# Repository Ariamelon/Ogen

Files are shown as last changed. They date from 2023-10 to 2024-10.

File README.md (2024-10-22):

# Ogen Lite
A PMW3360 breakout board. Lite version without shift registers which only works with up to 3v3 VCC and logic.

## Disclaimer
This board is licensed under CERN-OHL-S-2.0.

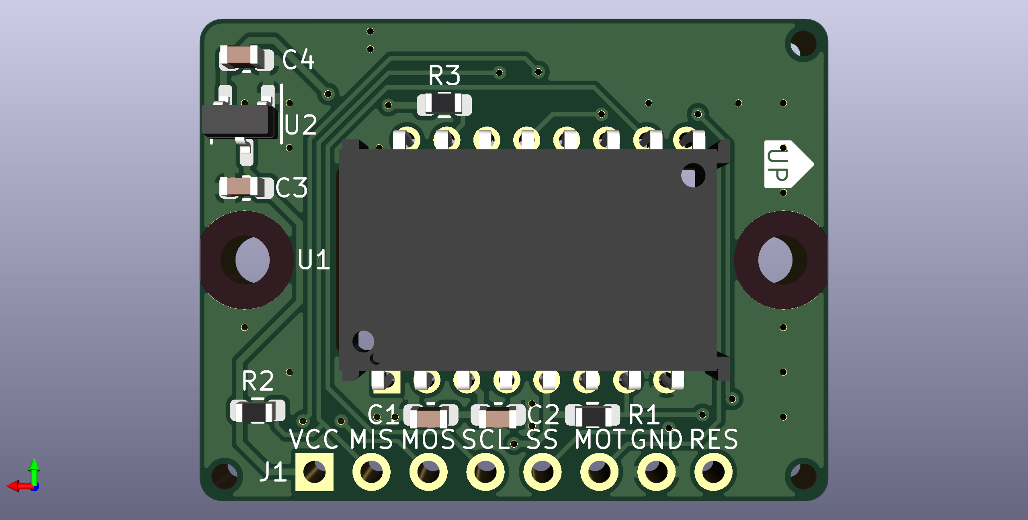
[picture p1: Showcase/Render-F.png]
Render Front

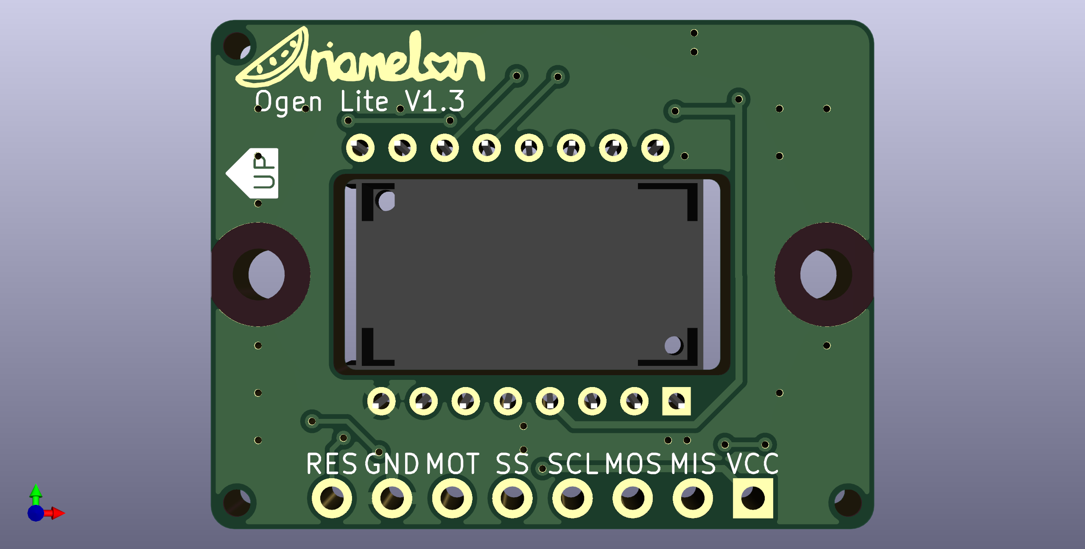
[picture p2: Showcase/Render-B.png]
Render Back


 ## Changelog
 * 22/10/2024: License updated to CERN-OHL-S-2.0.
 * 14/10/2023: V1.3 update. Changed LDO to XC6206P202MR.
 * 18/09/2023: Fixed .gitignore file. Changed LDO capacitors to 4u7 to match the one used in the PMW3360.
 * 04/08/2023: Updated to V1.1. Changed capacitors and resistors to 0603. Stitched ground planes together. Removed MISO pullup jumper (MISO is pulled up by default now). Added metadata to schematic and PCB file. Changed location of production files for easier access. 
 * 29/03/2023: Changed logo.
 * 21/03/2023: V1.0 Lite initial commit. No shift registers on board, hence works with 3V3 only.

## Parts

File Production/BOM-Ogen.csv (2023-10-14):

Comment | Designator | Footprint | LCSC
100n | C2 | C_0603_1608Metric | C14663
4u7 | C1,C3,C4 | C_0603_1608Metric | C19666
39 | R3 | R_0603_1608Metric | C25236
10k | R1,R2 | R_0603_1608Metric | C25804
XC6206P202MR | U2 | SOT-23-3 | C2891260
PMW3360DM-T2QU | U1 | IC_PMW3360DM-T2QU

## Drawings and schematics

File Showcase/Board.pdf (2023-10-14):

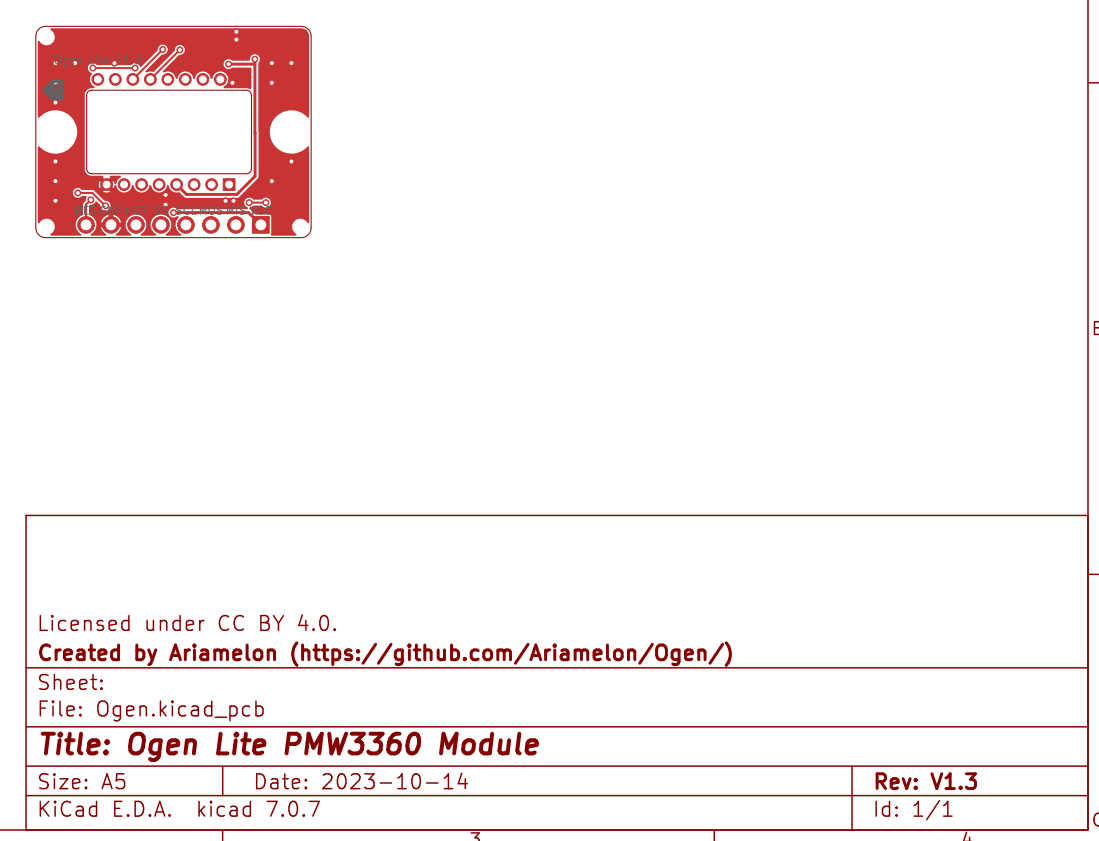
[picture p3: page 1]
MOT SS SCL MOS Ogen Lite V1.3 RESGND; MIS VCC 1; BC Date: 2023-10-14 KiCad; kicad; 7.0.7 Size: A5; Rev: V1.3; File: Ogen.kicad_pcb Sheet: Created; by Ariamelon; (https://github.com/Ariamelon/Ogen/) Licensed; under CC

Id: 1/1 Title: Ogen Lite PMW3360 Module

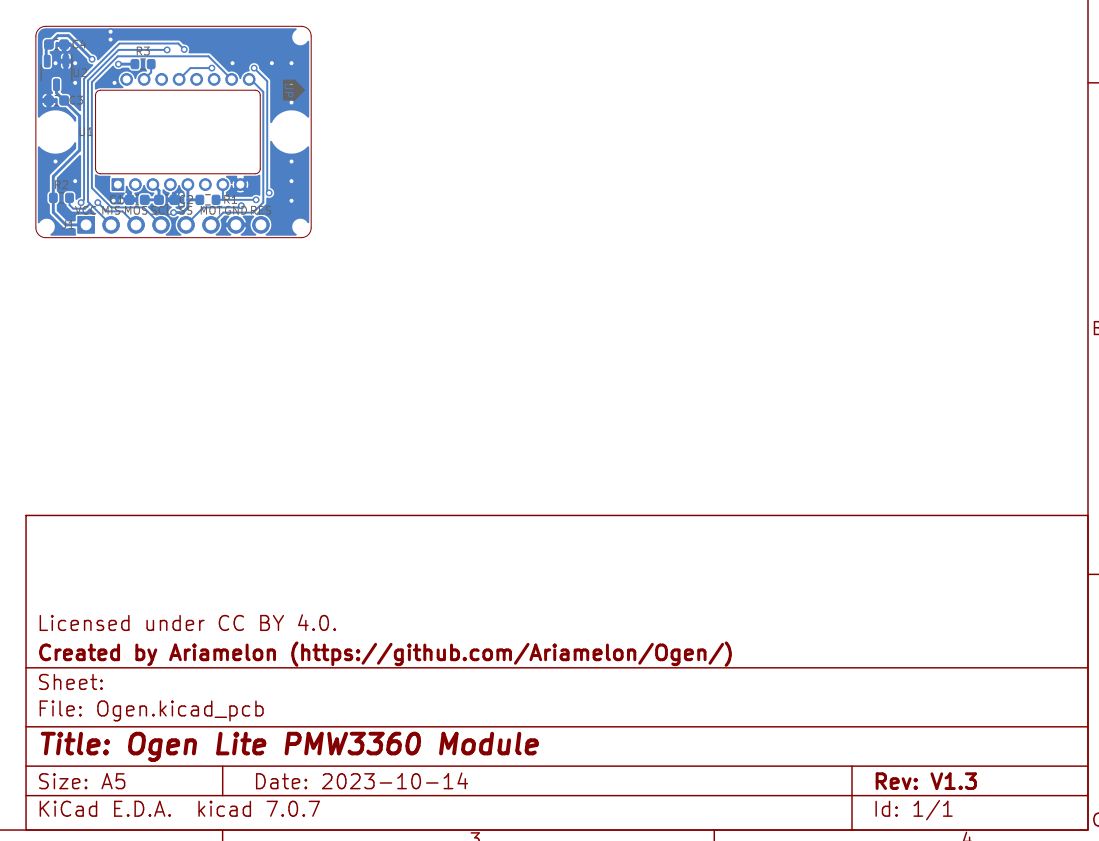
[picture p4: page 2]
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

Id: 1/1 Title: Ogen Lite PMW3360 Module

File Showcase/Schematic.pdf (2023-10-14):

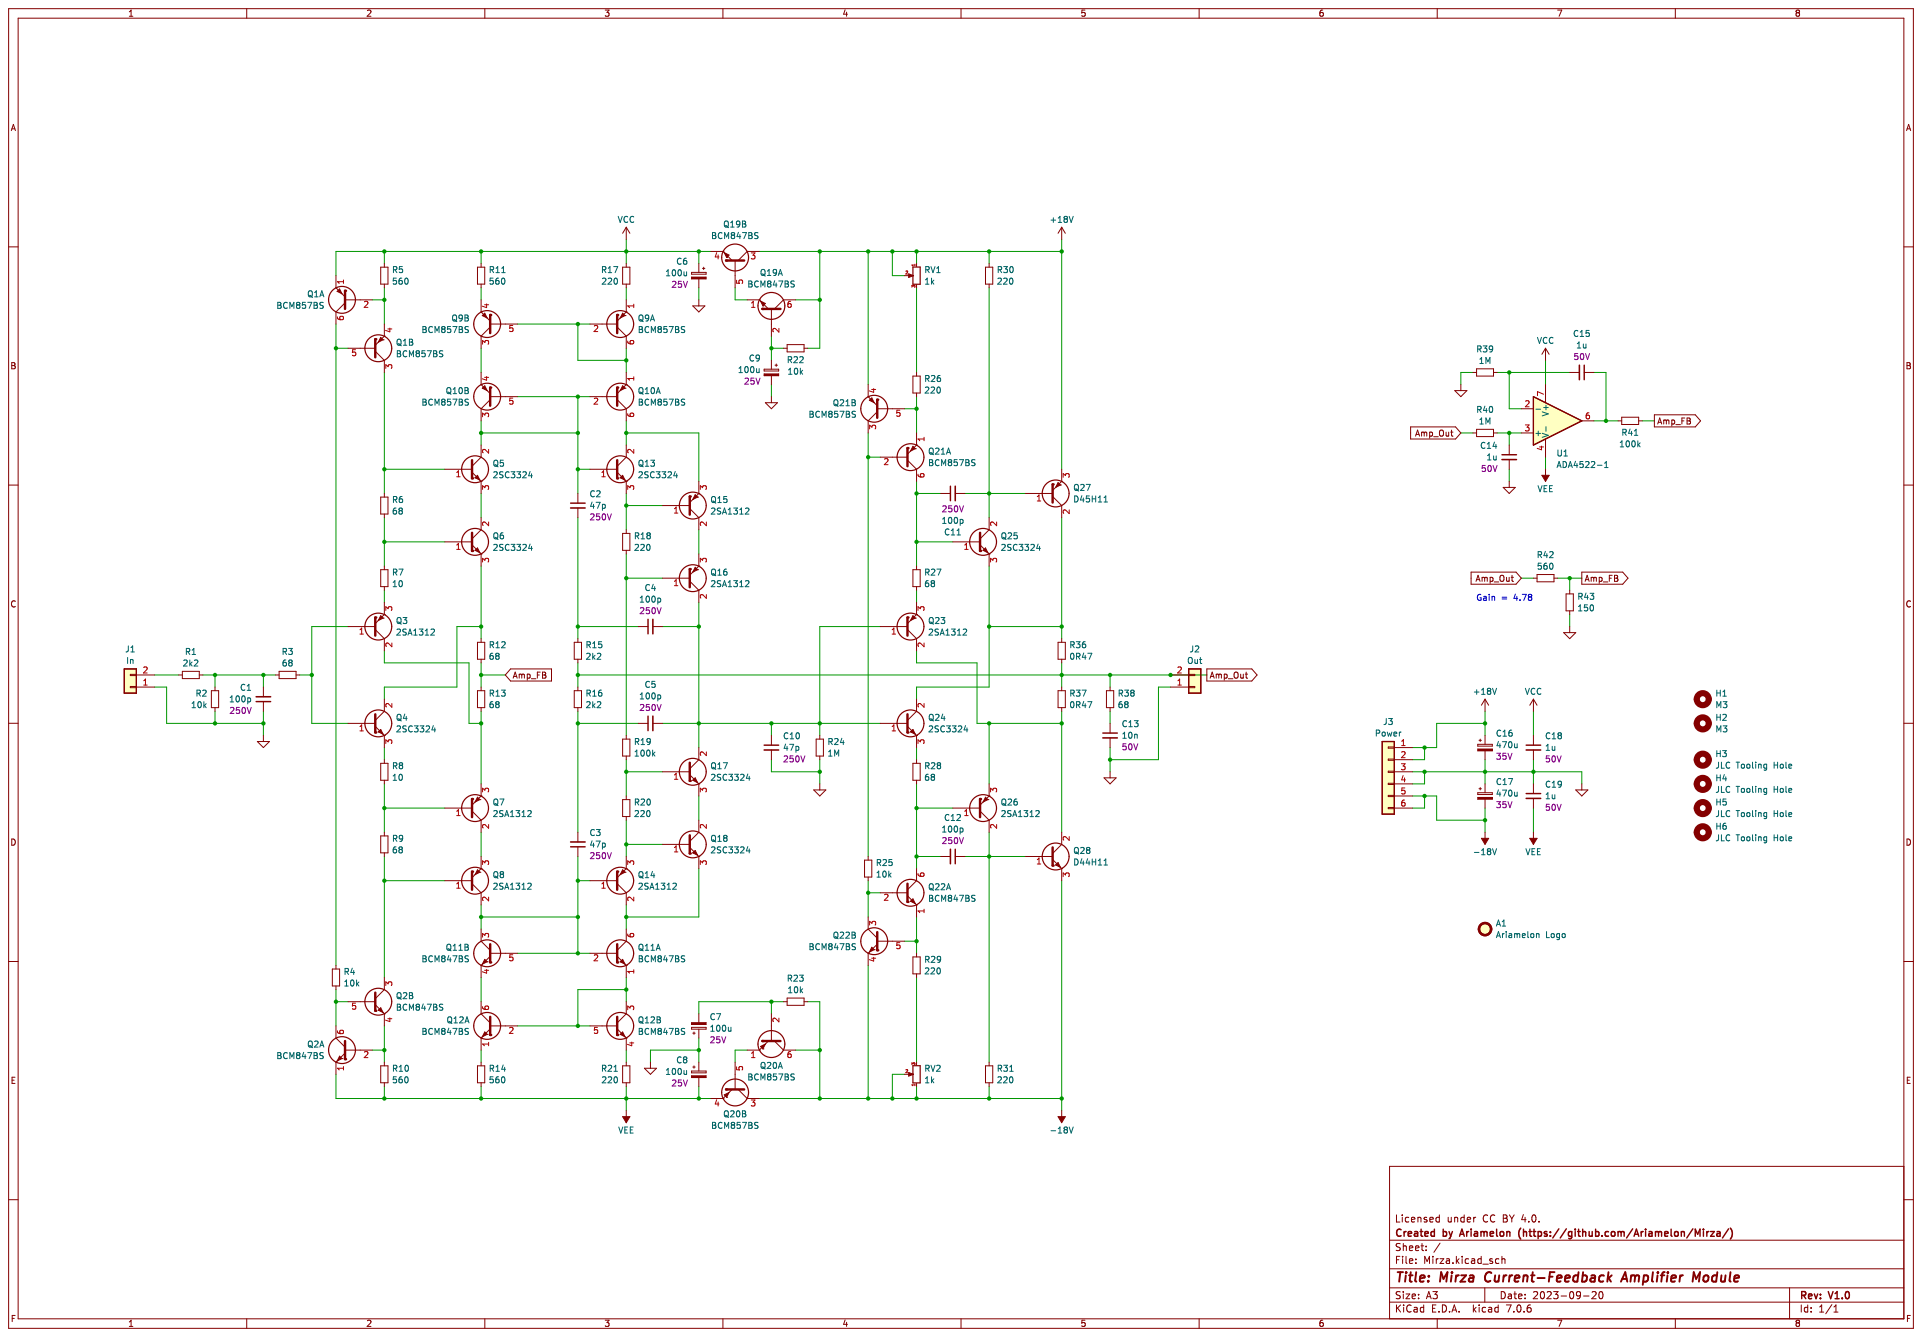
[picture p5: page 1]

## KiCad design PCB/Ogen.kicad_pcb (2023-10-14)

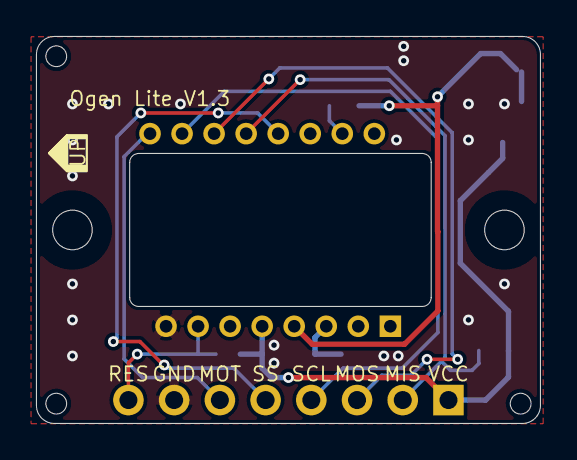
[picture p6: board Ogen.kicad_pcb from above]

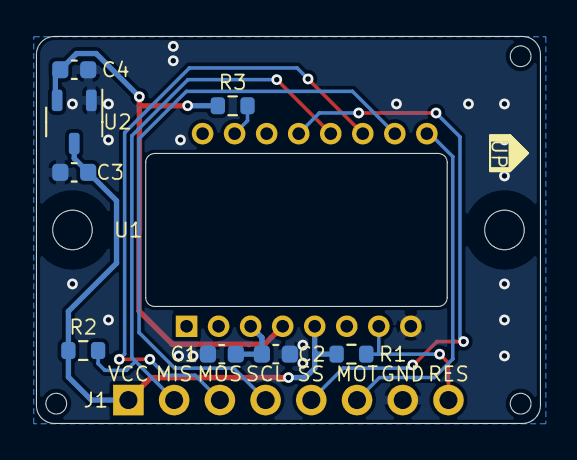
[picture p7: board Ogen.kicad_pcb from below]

Board: 2 copper layers, 28.0 x 21.5 mm, 16 parts (12 on the bottom side), 11 nets.

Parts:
A1: Art; Ariamelon_Logo-CU
C1, C3, C4: 4u7; C_0603_1608Metric
C2: 100n; C_0603_1608Metric
H1, H2: M2; MountingHole_2.2mm_M2
H3, H4, H5: Tooling Hole; JLC Tooling Hole
J1: Input; PinHeader_1x08_P2.54mm_Vertical
R1, R2: 10k; R_0603_1608Metric
R3: 39; R_0603_1608Metric
U1: PMW3360DM-T2QU; IC_PMW3360DM-T2QU
U2: XC6206P202MR; SOT-23-3

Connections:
+2V: C4.2, R3.2, U1.4 (VDD), U2.2 (VO)
+3V3: C3.2, J1.1, R1.2, R2.1, U1.5 (VDDIO), U2.3 (VI)
GND: C1.2, C2.1, C3.1, C4.1, J1.7, U1.8 (GND), U2.1 (GND)
MISO: J1.2, R2.2, U1.12 (MISO)
MOSI: J1.3, U1.11 (MOSI)
MOT: J1.6, U1.9 (MOTION)
NRESET: J1.8, R1.1, U1.7 (NRESET)
unnamed: R3.1, U1.15 (LED_P)
unnamed: C1.1, C2.2, U1.3 (VDDPIX)
SCLK: J1.4, U1.10 (SCLK)
SS: J1.5, U1.13 (NCS)

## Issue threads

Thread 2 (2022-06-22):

Is it 3.3V compatible?

EricDracula, 2022-06-22:
Hi, I wonder whether this pcb is 3.3V compatible.

Ariamelon, 2022-06-23:
Yes, the input voltage is limited by the maximum operating voltage of the high side of the level shifters, which is 5.5V.

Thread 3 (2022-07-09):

Old schematics

Doc303, 2022-07-09:
hello, I had ordered a handful of pcbs of the first version and now I would like to exploit them, could you send me the old schemes with the 5 shift registers at 1bit? I don't want to order more boards

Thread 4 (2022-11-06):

Alternative part for TLV70019

JeremyBois, 2022-11-06:
Hi,

I want to use [**JLCPCB**](https://jlcpcb.com/) service to print and assemble your board (thanks by the way !).

However the part `TLV70019` is out of stock ([TLV70019](https://jlcpcb.com/partdetail/TexasInstruments-TLV70019DDCR/C2862411)) and I am looking for an alternative.
I found one which seems equivalent and in stock ([VRH1902LTX](https://jlcpcb.com/partdetail/Anasem-VRH1902LTX/C697975)).

Can you tell me if [VRH1902LTX](https://jlcpcb.com/partdetail/Anasem-VRH1902LTX/C697975) can be used in place of [TLV70019](https://jlcpcb.com/partdetail/TexasInstruments-TLV70019DDCR/C2862411) ?

Have a nice day,

JeremyBois, 2022-11-20:
I made a [fork](https://github.com/JeremyBois/Ogen) with:
  - [VRH1902LTX](https://jlcpcb.com/partdetail/Anasem-VRH1902LTX/C697975) in place of [TLV70019](https://jlcpcb.com/partdetail/TexasInstruments-TLV70019DDCR/C2862411)
  - BOM and POS files as required for JLCPCB assembling service
  - Embed datasheet for VRH1902LTX and PMW3360DM-T2QU parts

The PCB is in production right now. I will update / close this issue once I can confirm that the modification does work.

BenRoe, 2023-01-31:
@JeremyBois does it work with the VRH1902LTX ?

JeremyBois, 2023-02-05:
> @JeremyBois does it work with the VRH1902LTX ?

Not yet tested.
I receive the PCBs and I am working on the QMK configuration for my keyboard right now.
When the trackball will be fully working I will close this issue.

JeremyBois, 2023-02-14:
I can confirm that the sensor does work with VRH1902LTX part as a replacement.
Tested on my [keyboard with QMK](https://github.com/JeremyBois/qmk-ptechinos/tree/KB2040).

Feel free to use my [fork](https://github.com/JeremyBois/Ogen) for manufacturing.

buitrung, 2023-02-28:
Hi @JeremyBois, I find your repo really useful.
However I'm new to these pcb things, so please help me with my dumb question.

Is it that I can upload your [gerber file](https://github.com/JeremyBois/Ogen/blob/main/PCB/data/production/V1.2/OgenV1.2-Gerbers.zip) to JLC and check the option "PCB assembly" and that's all?
Does your board will come with every little part on it?
Does it come with the main sensor or do I have to get it separately then solder on the board?

Thanks for your help.

buitrung, 2023-02-28:
I've just play around with JLC and seem to have figured this out...
I upload your v1.2 gerber file, then upload the bom.csv & positions.csv for BOM & CPL in the BOM screen and get the final result in a 2d/3d renderer, in which the main sensor is missing (I may possibly solder it by myself).

Thanks for your fantastic work!

JeremyBois, 2023-02-28:
> Does your board will come with every little part on it?

All but the sensor and its lens.

> Is it that I can upload your [gerber file](https://github.com/JeremyBois/Ogen/blob/main/PCB/data/production/V1.2/OgenV1.2-Gerbers.zip) to JLC and check the option "PCB assembly" and that's all?

You need to upload:
  - gerber files
  - bom.csv
  - positions.csv

> Does it come with the main sensor or do I have to get it separately then solder on the board?

No the sensor and lens have to be bought separately (JLC manufacturing service is only for SMD parts).

> I upload your v1.2 gerber file, then upload the bom.csv & positions.csv for BOM & CPL in the BOM screen and get the final result in a 2d/3d renderer, in which the main sensor is missing (I may possibly solder it by myself).

Yes you understand it correctly. Please double check that each component is in the right position / orientation before processing further (just in case). On each part there is a little circle (see github PCB images) which show where the first pin should be. If I remember correctly there JLC use a red circle to show where the first pin will be.

If you are unsure feel free to ask.

buitrung, 2023-03-02:
Good to know to confirm the correct orientation of parts. I did not do that but the result was still correct. I have placed the order and will confirm if it works (or even not).

Closed 2023-06-25.

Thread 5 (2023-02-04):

connecting to arduino micro pro

vik523, 2023-02-04:
I try connect this board on arduino micro pro.
  RS --- (NONE)
  GD --- GND
  MT --- Pin_7
  SS --- Pin_10   (use this pin to initialize a PMW3360 instance)
  SC --- SCK
  MO --- MOSI
  MI --- MISO
  VI --- 5V
I use next conection https://keycapsss.com/media/pdf/c4/fa/cc/kycs-pmw3360-help-sheet.pdf
and I tried next firmware: https://github.com/mrjohnk/PMW3360DM-T2QU and qmk. In code I check SS conection (it corresponds to pin 10).
I dont connect Jumper. The device is not recognized in the system. How can you figure out what the problem is? I will be glad for any advice.

Ariamelon, 2023-08-04:
Have you soldered the MISO pullup jumper? Maybe that could be the cause for it not working.

vik523, 2023-08-14:
I tried both options with and without a jumper. I have already purchased a device for receiving a signal from the board, but have not yet understand how to test it.

Ariamelon, 2023-08-14:
Hmm, maybe check the connections of your PMW3360...

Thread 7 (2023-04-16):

PCB working but not with longer jumper cables

rftw, 2023-04-16:
I got V1.2 pcbs from jlcpcb. Bought sensor lens from [aliexpress ](https://www.aliexpress.us/item/2255800717950849.html). Soldered it on the pcb and connected it to blue promicro using 7.5cm (3") F-F jumper cables. Working great.

However when using jumper wires greater than 10cm, it's not working. The sensor is getting the power. I can see the red light from an angle, but there is no movement. I also have [MrJohnK pcb from tindie](https://www.tindie.com/products/jkicklighter/pmw3360-motion-sensor/). With MrJohnK pcb, and nothing else changed in the setup (jumper wires, blue promicro), the sensor started working even with jumper cables >30cm. Your pcb is working only with <10cm wire.

What could explain this behavior?

rftw, 2023-08-24:
I soldered the jumper but it seems to have no effect. The breakout is working great with sockets or with smaller length jumper cables. Must have been gone something wrong with the jlcpcb assembly.
I noticed you've made some design modifications. I'll soon give it a try.
Thank you for this amazing repo!

Closed 2023-08-24.

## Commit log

2020-09-29 Fixed traces
    Some traces weren't the right width so I fixed that. ALso did some minor rerouting.
    [Ogen-B_Cu.gbr, Ogen-B_Mask.gbr, Ogen-B_Paste.gbr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]
2020-10-01 Added images and updated readme
    [Ogen.kicad_pcb]
2020-10-04 Fixed major flaw in PMW3360 footprint
    [Ogen-B_Cu.gbr, Ogen-B_Mask.gbr, Ogen-B_Paste.gbr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]
2020-10-24 Updated silk, better render
    [Ogen.kicad_pcb]
2022-06-23 Updated to V1.1
    [Ogen-B_Cu.gbr, Ogen-B_Mask.gbr, Ogen-B_Paste.gbr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]
2023-03-21 V1.0 Lite initial commit.
    [BOM-Ogen.csv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]
2023-03-29 Update README.md f
    [CPL-Ogen.csv, Ogen-CuBottom.gbr, Ogen-CuTop.gbr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]
2023-03-29 Changed logo.
    [CPL-Ogen.csv, Ogen-CuBottom.gbr, Ogen-CuTop.gbr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]
2023-08-04 04/08/2023 update
    Updated to V1.1. Changed capacitors and resistors to 0603. Stitched ground planes together. Removed MISO pullup jumper (MISO is pulled up by default now). Added metadata to schematic and PCB file. Ch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
    [BOM-Ogen.csv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]
2023-09-18 18/09/2023 update
    Fixed .gitignore file. Changed LDO capacitors to 4u7 to match the one used in the PMW3360.
    [BOM-Ogen.csv, Ogen.kicad_pcb, Ogen.kicad_sch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]
2023-10-14 V1.3 update
    Changed LDO to XC6206P202MR.
    [BOM-Ogen.csv, Ogen.kicad_pcb, Ogen.kicad_sch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]

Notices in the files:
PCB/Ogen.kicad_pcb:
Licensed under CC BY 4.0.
